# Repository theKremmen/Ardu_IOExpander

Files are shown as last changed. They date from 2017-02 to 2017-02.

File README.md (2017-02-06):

Ardu_IOExpander README.
# A Really Poor Man's Programmable Logic Controller
The library plc.h/plc.cpp together with the associated IOExpander board implement a small open source/hw logic simulator. It is free for any use but comes with no warranties of any kind.
The functionality is open ended such that it is easy to implement additional logic blocks or port the whole gizmo to a more powerful platform (Arduino Due, ST Nucleo, maybe?).

## Configuring the PLC

Configure the PLC by editing the settings in "plcconfig.h" as follows:

**TIMERTICK:** ( default `#define TIMERTICK 1000 `).

The resolution of the timers in components that time something.
The interval is given in microseconds, thus smaller is quicker.
The default value 1000 is one tick every millisecond.
All components share the same tick so select a value that is small enough but no smaller. Too small interval will overload the processor

**SPICLOCK:** ( default `#define SPICLOCK 1000000` )

The clock rate of the SPI serial clock that transfers input and output bits. Default is 1000000 i.e. 1 MHz. There should be no need to adjust this but you may if there is a need.

**BITSPACE:** ( default `#define BITSPACE 32` )

Memory space allocated for bit variables of the "ladder" logic One bit of memory is allocated for each bit variable. You can have bit variables numbered from 0 to (8 * BITSPACE)-1 E.G. if BITSPACE = 32, then your bit index goes from 0 to 255.

NOTE!: The software assigns the physical input signals to bits 0...15 and bits 16...31 to the physical OUTPUTS. The rest are freely available for programming.
You may use OUTPUTS as inputs to logic elements, but you may **NOT** use INPUTS ( bits 0 ... 15) as outputs. (You can, but it won't work).

    #if BITSPACE <= 32
    typedef uint8_t logicBit;	// type for bit variable references
    #else
    typedef uint16_t logicBit;
    #endif
    
Also note that if you specify a bitspace > 32 bytes in size, the size of the bit reference changes fron uint8_t to uint16_t. This has not been tested so surprises are possible.

**INTSPACE:** ( default `#define INTSPACE 16` )

Memory space allocated for numeric variables related to timing, counting etc.

One uint16_t is allocated for each numeric. Be sure to check the number of variables a logic component reserves. As a rule, the bit operations do not reserve any numeric variables, neither do static timers or counters (where the timing or count is constant).

Variable timers and counters need 1 or more. A multiplexer uses 3 or 5

    typedef uint8_t numeric;	// type for numeric variable references

**MAXTIMERS:** ( default `#define MAXTIMERS 8` )

The maximum number of timers reserved for the program
Make sure this number is equal or larger than the actual number of timers used by all timing components together.
As a general rule, any delay or pulse will use 1 timer.

**MAXCOMPONENTS:** (default `#define MAXCOMPONENTS 64` )

The maximum number of components allowed in the program. 
The list of components you create is maintained in a fixed size pointer array to avoid dynamic allocation and to minimize the list iteration runtime.

Make sure this number is larger or equal to the actual number of all ladder components in your application (anything you create using 'new').

**INVERT_INPUTS:** ( default `#define INVERT_INPUTS` )

Optionally you can invert the sense of all inputs by defining this (the default is `#define`d )
All input '1's will turn to '0's and vice versa.

The IOExpander physical inputs are active low with internal pullup. Unconnected, the input will be pulled to +5V, i.e. '1' or 'high' and the LED will be dark. That is what the program sees if there is nothing connected to the input. The input LED illuminates when the input signal wire is grounded. This causes the program to read a '0' from the input. It works but reversing the input in the program makes it easier for the programmer. Also, the logic modules are clocked on signal rising edges.

So, when the inputs are inverted, grounding an input pin will cause the program to see a logic '1' in the corresponding input signal.

## Arduino

You need to install an ***original Arduino Micro*** or an ***exact clone***. Only those will have the SPI signals in the module pins. This feature is not configurable, so take care. There are lots of various "Arduino Micro Pro" modules and similar with different pinout in eBay and elsewhere - **those will not work!** Specifically, you cannot use an Arduino Nano as it does not have the necessary SPI signals in the pinout.

Install the Arduino so that the USB connector faces the board edge. You can solder the Arduino directly on the board or use a set of female headers if you wish to remove the module at some time. Programming can be done with everything in place, though.

## Power and signal wiring

1. Connect the supply ( +12VDC ) to the 2 position connector block in the lower middle of the board (when oriented so that the Ardu USB connector is facing up). Positive wire is the left one, ground the right. The supply is protected against reversed polarity.

2. Connect the sensors to the 3 pin headers on the left. The pins are marked on the silkscreen thus: [+ s -] where +: +5V supply to an active sensor; s: input signal ( 0...+5V ) to the PLC; -: ground. The input signal activated upon grounding the signal pin. Connecting the signal pin to +5V does nothing, but take care not to short the +5V and ground pins!

3. Connect the outputs to the right hand side 2 pin connectors. If the polarity matters, the positive pin is on the right when looking towards the board from outside. Take care not to short the positive pins to ground as there is no overcurrent protection on the expander board! (one hopes there is a current limit in the +12V supply you use).

## Bonus I/O

Most of the regular Arduino Micro digital and analog I/O signals have been brought out next to the Ardu module into normal through hole pads.

Digital signals D4 ... D10 can be found on the right side in a .1" pin header with a ground pin topmost. Use as you please with an extra header or solder the wires directly on board.

Similarly, analog signals A0 ... A5 can be found on the left side in a 3 pin header each. Pin 1 (rightmost, square pad) of each header is +5V for a pot or sensor or whatever, and the leftmost pin (3) is ground. The analog input is from pin 2 and there is a small RC lowpass connected to each input. Again, to avoid magic smoke do not short the +5V pins.

Be aware that the Arduino analog signals are pretty noisy and the base electronics don't really address that issue. So you need to take that into account when designing a PLC app that uses the analog values for something.

A solder pad to the left of the analog inputs, marked as 'Vref', is connected (surprise) to the analog reference pin of the MCU. Use as you wish or leave open. Also, close by is a pad marked 'D201' that connects to I/O pin D13 and the LED on board the Arduino. Now you can easily replicate the LED! Finally, on the other side of the Ardu there is a pad 'SS' that connects to USART_RXLED/SS. If you find a use for that, go right ahead.
 
Additinally, the board includes placeholders for I2C connectors and and SPI expansion to enable connecting units in series. These have not been tested but there should be no reason why they wouldn't work. If you need them, presumably you know what to do. Look to the right side of the Ardu module and you will find 2 solder bridges marked 'I2C TERM'. Shorting those will activate the 4.7k pull-up termination for the I2C bus.

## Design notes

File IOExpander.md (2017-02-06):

# Tosi Köyhän Miehen logiikkasimu Arduinolle

plc.h/plc.cpp yhdessä IOExpander-laajennuspiirilevyn kanssa toteuttaa pienen avoimen logiikkasimulaattorin.
Määriteltyjä toimintoja on mahdollista muokata tarpeen mukaan sekä toteuttaa kokonaan uusia toimintoja.
Seuraavassa lyhyt läpikäynti ohjelman ominaisuuksista ja toiminnasta.

## PLC:n konfigurointi

Konfigurointi tehdään asettamalla tiedoston "plcconfig.h" sisältämät #define -määritykset haluttuihin arvoin.
Niiden merkitys on seuraava:

TIMERTICK: ( oletusarvo #define TIMERTICK 1000 )
Logiikkaohjelman käyttämien ajastimien ja pulssigeneraattoreiden aikaresoluutio millisekunteina.
Ohjelma ei mitenkään testaa annetun arvon järkevyyttä, joten kannattaa varoa laittamasta liian pientä arvoa.
Totuus selviää kyllä kokeilemalla.

SPICLOCK: ( oletusarvo #define SPICLOCK 1000000 )
Tuloja ja lähtöjä ohjaavien siirtorekisterien kellotaajuus. Oletusarvo on 1MHz eikä tätä ole normaalisti tarvetta muuttaa.

BITSPACE: ( oletusarvo #define BITSPACE 32 )
Logiikan bittimuuttujille varattu muistitila. Jokainen muuttuja vie yhden bitin verran tilaa muistissa (mikä yllätys).
Ohjelma pystyy siis käsittelemään bittejä 8 * BITSPACE määrän, eli oletusarvoisesti 256 bittiä (signaalia).
Huomaa, että fyysiset tulosignaalit luetaan bittimuuttujiin 0...15 ja fyysiset lähtösignaalit kirjoitetaan bittimuuttujista 16...31.
Huomaa myös, että mikäli BITSPACE > 32, kaikki ohjelman signaaliviittaukset muuttuvat 8-bittisistä referensseistä 16-bittisiksi eikä tätä ole kunnolla testattu:
    
    #if BITSPACE <= 32
    typedef uint8_t logicBit;	// type for bit variable references
    #else
    typedef uint16_t logicBit;
    #endif
    
INTSPACE: ( oletusarvo #define INTSPACE 16 )
Logiikan numeerisille muuttujille varattu tila. Kaikki numeeriset muuttujat ovat etumerkittömiä 16-bittisiä kokonaislukuja ( uint16_t ). Muuttujatilaa kannattaa varata riittävästi, mutta ei liioitellusti koska RAM-muisti on kortilla pikku Arduinossa. Kunkin logiikkamodulin tarvitsema tilavaraus on mainittu sen esittelyssä.

MAXTIMERS: ( oletusarvo #define MAXTIMERS 8 )
Tilavaraus logiikan ajastimille. Varaus tehdään samalla periaatteella kuin yllä.

MAXCOMPONENTS: ( oletusarvo #define MAXCOMPONENTS 64 )
Tilavaraus komponenttilistalle. Määrittelemässäsi logiikkaohjelmassa voi olla enintään näin monta yksittäistä modulia. Älä ylitä tätä lukemaa!
Kaikki Arduinon setup():issa luodut logiikkalohkot lisätään yksinkertaiseen jonolistaan, josta ne suoritetaan peräjälkeen jokaisella loop():in kierroksella. Toteutus on tehty näin yksinkertaisuuden ja suoritustehokkuuden takia. Joudut kuitenkin olemaan lievästi huolellinen, eli laskemaan, että määrittelemäsi lohkot mahtuvat listalle. Jokainen lohko siis vaatii yhden listaelementin. 

INVERT_INPUTS: ( oletusarvo #define INVERT_INPUTS )
Mikäli määritys INVERT_INPUTS on tehty, jokainen tulosignaali käännetään ympäri, eli looginen '1' muuttuu '0':ksi ja päinvastoin.
HUOMAA, että IOExpanderin tulosignaali on aktiivinen alaspäin, eli ledi valaisee kun tulosignaalin tila on '0'.
Kun signaali on '1' tai kytkemätön, ledi ei pala. Ohjelmaan välittyy kuitenkin kyseinen tila, eli kytkemätön tulo luetaan '1'-tilaiseksi. Useimmiten tämä ei ole toivottua, vaan signaali halutaan tulkita niin, että se on '1' kun ledi valaisee. Siispä invertoidaan tulot jolloin ajatus toteutuu. Jos invertointia EI haluta käyttää, riittää että tämä #define kommentoidaan pois: //#define INVERT_INPUTS

## Arduino

PLC haluaa expanderikortille Arduino Micron. Ole tarkkana minkä kapineen kortille länttäät, koska kaikki eBay-tavara yms ei ole originaalispeksin mukaista. Käytetyn Ardun pinnijaon pitää olla 1:1 originaali Arduino Micron kanssa - esim. Arduino Nano EI KÄY. Micro on valittu koska vain siitä saa välttämättömän SPI-väylän suoraan ulos pinneistä. Ardu asennetaan siten, että sen USB-liitin tulee kohti piirilevyn ulkoreunaa. Moduli nvoi juottaa suoraan kiinni tai mikäli haluaa varmistella, niin voi käyttää myös korokeheadereita jolloin Ardun saa vielä irtikin.
Arduinon voi ohjelmoida etuykäteen, tai se onnistuu myös piiri kiinnitettynä jolloin sitä varten irroitettavuutta ei tarvita. 

## Sähköiset kytkennät

1. Syöttöjännite ( n. 12V) kytketään kortin "alareunassa" keskellä olevaan pieneen riviliittimeen. Positiivinen johto vasemmalle, maa oikealle. Liitäntä on suojattu väärää napaisuutta vastaan.
2. Anturit kytketään vasemman reunan 3-pinnisiin pistoliittimiin. Liittimet on merkitty silkkipainoon [+ s -] ja samassa järjestyksessä signaalit ovat: +: +5V syöttö anturille; s: tulosignaali (+5V <-> 0V); -: 0V syöttö anturille. Tulosignaali aktivoituu kun s-pinni maadoitetaan - pinniin. s-pinnin kytkeminen + pinniin ei tee mitään, mutta VARO oikosulkemasta + ja - pinnejä keskenään.
3. Lähdöt kytketään oikean reunan 2-pinnisiin liittimiin. Oletus on, että kuorma on solenoideja tms joiden napaisuudella ei ole väliä, mutta jos on, niin lähdön +-napa on piirilevyn ulkoreunasta sisäänpäin katsoen oikeanpuoleinen pinni. Vasen menee kytkinfetille ja siitä maahan. VARO siis oikosulkemasta oikeanpuoleisia pinnejä maahan koska niissä on koko ajan jännite ja laitteessa ei ole ylivirtasuojausta (toivottavasti käyttämässäsi virtalähteessä on).

## Lisäkytkennät

Ardu Micron normaalit digitaaliset ja analogiset I/O-piirit on tuotu expanderille Ardumodulin viereen juotosreikiin.
Digitaalisignaalit D4 ... D10 on tuotu suoraan 0,1" reikäriviin jonka viimeinen reikä (D10 puoleinen pää) on maajännite. Tähän voi kolvata johtimia suoraan tai laittaa headerin protojohtoja varten.
Vastaavasti analogisignaalit A0 ... A5 on tuotu Ardun vasemmalle puolelle kukin 3-reikäiseen headerpaikkaan. Headerin pinni 1 (neliötäppä, oikeanpuoleinen) on +5V syöttö esim potikalle, pinni 3 (vasen) on maa.  Analogisignaali luetaan keskipinnistä 2 ja siihen on kytketty pieni RC-suoto nappaamaan pahimmat jännitepiikit pois. HUOMAA kuitenkin, että analogisignaalit kohisevat aina eikä logiikkaohjelman analogitulolohkossa ole varsinaista suodatusta koska se on raskasta puuhaa prosessorille. Älä siis kuvittele, että signaalit olisivat ideaalisen rauhallisia, vaikka olisit kytkenyt pelkän potikan tuloon.
Juotostäppä Aref edellisten vasemmalla puolella on kytketty (yllätys) prosessorin analogireferenssiin. Sitä voi käyttää datalehden mukaisesti mikäli taretta ilmenee.
Edellisen vieressä on toinenkin tuotostäppä, merkattu D201. Se on kytketty Arduinon digitaalilähtöön D13, joka puolestaan on kytketty Ardumodulin lediin.
Piirilevyn laidasta Ardun toisella puolella löytyy vielä täppä "SS" joka on kytketty signaaliin RX_LED/SS.

Edellisten lisäksi expanderilta löytyy liitinpaikat I2C-väylälle ja SPI-väylän laajennukselle, tarkoituksena mahdollistaa useampien expanderien kytkeminen ryhmään. Näitä ei ole testattu mitenkään, joskaan ei ole mitään erityistä syytä miksi eivät toimisi. Joka niitä tarvitsee osaa varmaan käyttää niitä ilman erityisempää ohjeistusta tässä. Ardun oikealta puolelta löytyy 2 kpl juotos-oikosulkutäppiä jotka merkattu "I2C TERM.". Juottamalla nämä umpeen saadaan voimaan I2C-väylän 4,7kohm ylösvetoterminointi.

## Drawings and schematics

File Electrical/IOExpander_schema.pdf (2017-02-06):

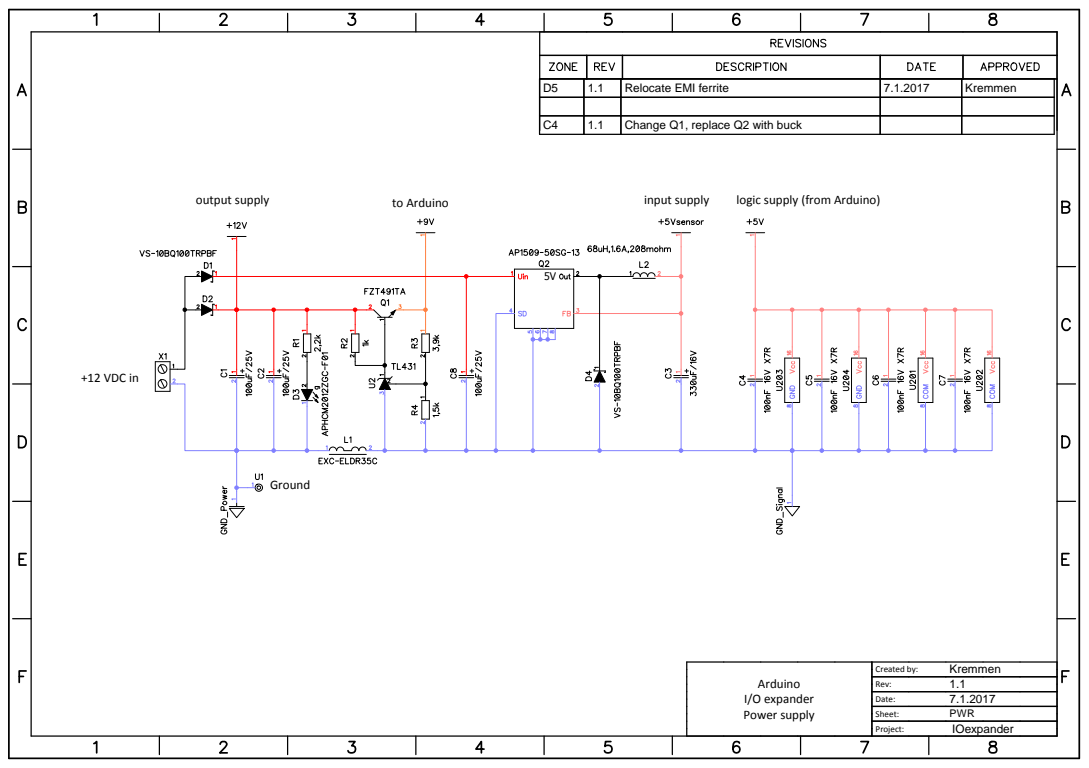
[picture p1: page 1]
+12 VDC in; to Arduino output supply; input supply; logic supply (from Arduino); Ground; Kremmen; PWR; Created by:; Rev:; Date:; Sheet:; Kremmen 1.1 7.1.2017; Project:; IOexpander; Arduino I/O expander Power supply

Relocate EMI ferrite

Change Q1, replace Q2 with buck

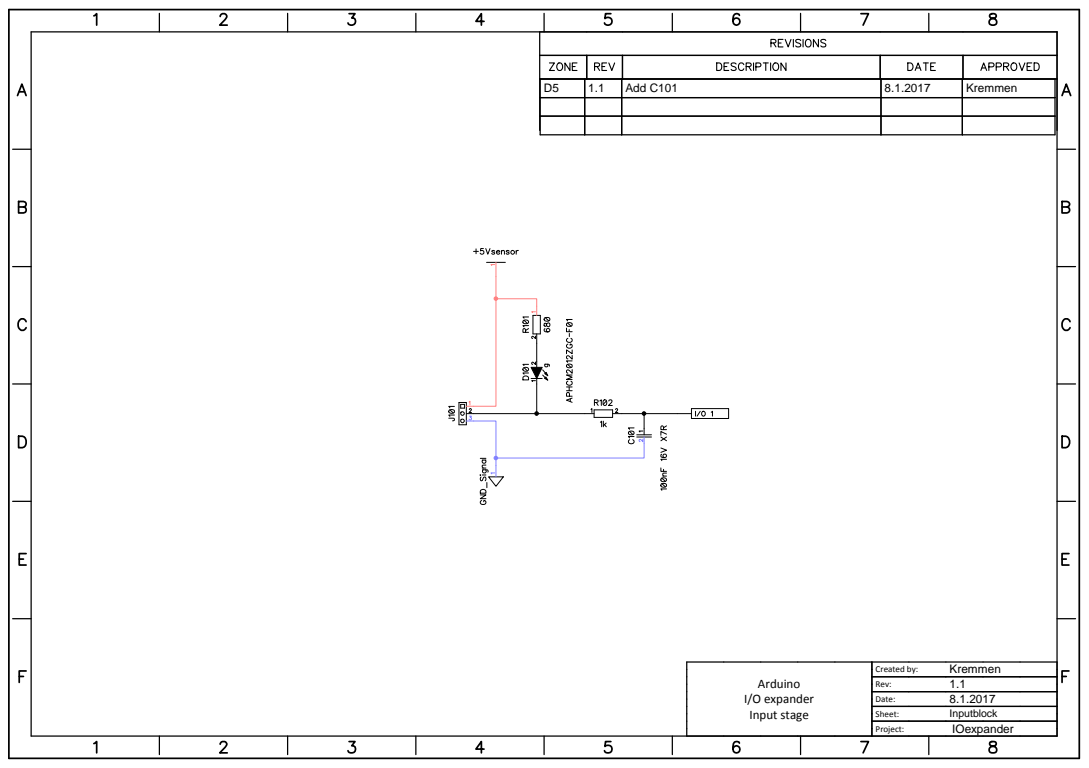
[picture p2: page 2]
Add C101; Kremmen; Inputblock; Created by:; Rev:; Date:; Kremmen 1.1 8.1.2017; Arduino I/O expander Input stage

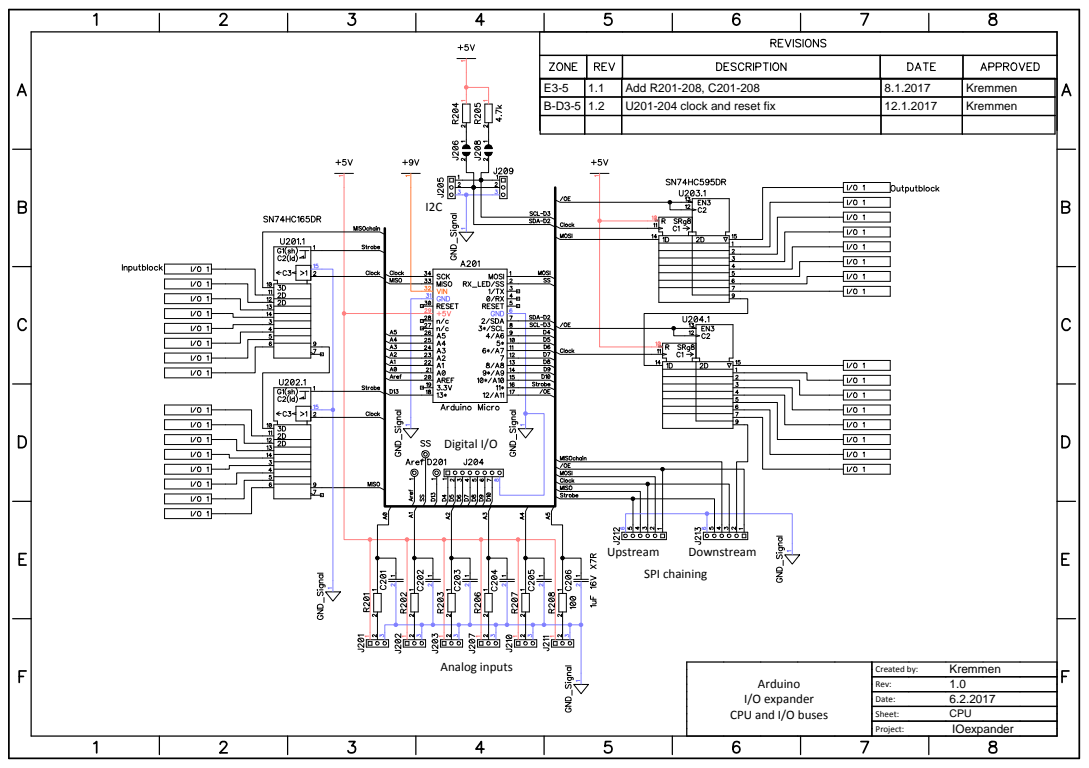
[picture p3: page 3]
Upstream; Downstream; SPI chaining; Analog inputs; Digital I/O; CPU; Created by:; Rev:; Date:; Kremmen 1.0 6.2.2017

E3-5 | 1.1 | Add R201-208, C201-208 | 8.1.2017 | Kremmen
B-D3-5 | 1.2 | U201-204 clock and reset fix | 12.1.2017 | Kremmen

Arduino
I/O expander
CPU and I/O buses

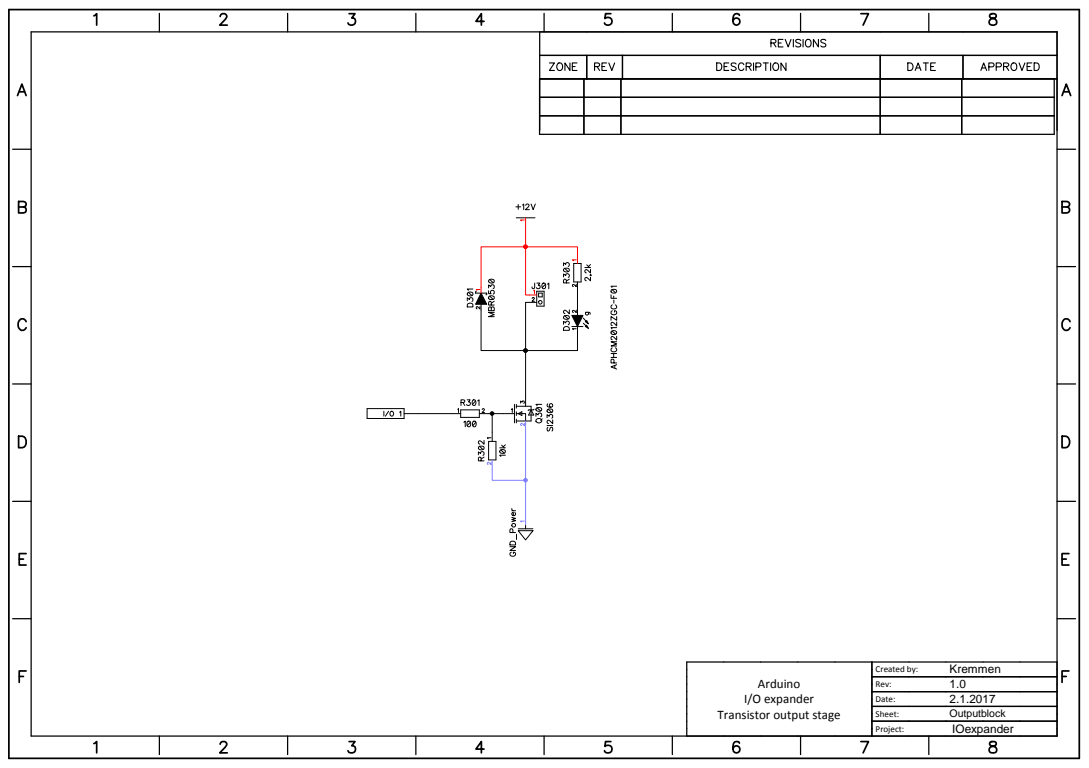
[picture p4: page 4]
Outputblock; Created by:; Rev:; Date:; Kremmen 1.0 2.1.2017

Arduino
I/O expander
Transistor output stage

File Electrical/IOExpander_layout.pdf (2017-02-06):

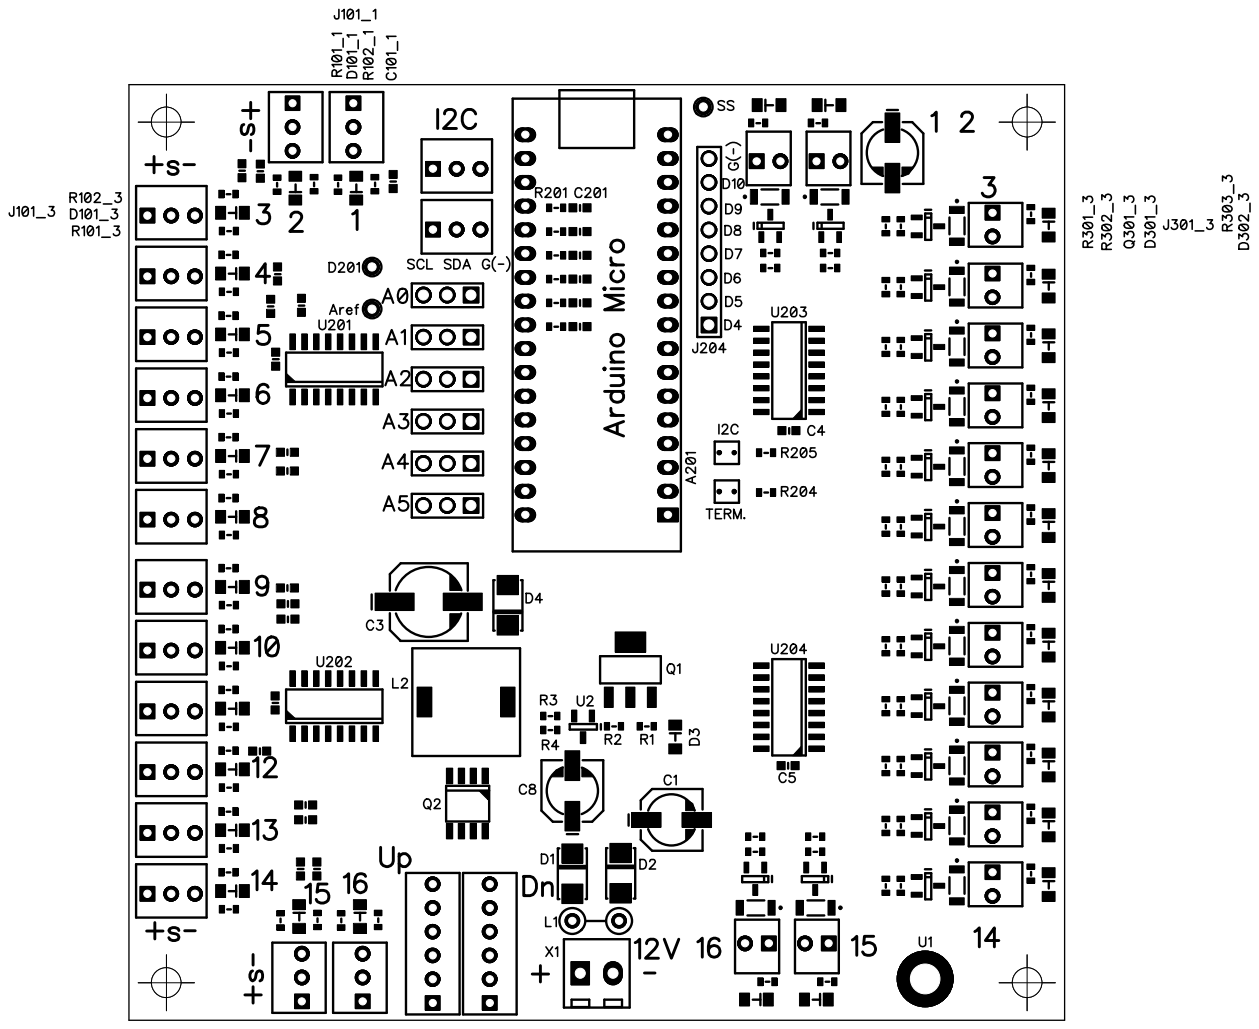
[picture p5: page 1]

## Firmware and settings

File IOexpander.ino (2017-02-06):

// Arduino IO expander using Arduino Micro
// Author: Kremmen 12.1.2017
// Tämä on pieni esimerkkisovellus jossa on käytetty useimpia, mutta ei välttämättä kaikkia
// plc-simulaattorin toiminnallisia lohkoja.
// Lopullinen totuus selviää tiedostoja plc.h ja plc.cpp lukemalla, siellä on kommentoitu tarkemmin kunkin
// toiminnon olemusta.

// Arduinon käännösympäristö vaatii nämä esittelyt vaikkei niitä käytetä tässä
#include <TimerOne.h>
#include <SPI.h>

// Varsinainen logiikkasimu on täällä
#include "plc.h"


// Arduinon normaali setup: Koko logiikkaohjelma määritellään setupissa luomalla tarvittavat logiikkalohkot
// Luonti tapahtuu C++ -kielen muistioperaattorilla 'new'. Älä määrittele lohkoja muilla tavoilla koska
// vain tämä tapa on testattu toimivaksi
// Kunkin lohkon parametrit viittaavat bittisignaaleihin ja/tai numeerisiin muuttujiin. Viittaus on kunkin
// järjestysnumero k.o. muuttuja-avaruudessa. Kts tarkemmin "plcconfig.h".
// Tämä esimerkki ei tee mitään järkevää, sen tarkoitus on vain demota kuinka ohjelma rakenetaan lohkoista.

void setup()
{
	CList.begin();		// aloita aina tällä lauseella! Se mm. alustaa kaikki lähdöt passivitilaan mahdollisimman nopeasti

	Serial.begin(115200);
	Serial.println("ArduPLC v 1.0");


	setBit(255, true);
	setBit(254, false);
	setInt(15, 511);
	setInt(14, 100);

// Ensimmäinen monostabiili; tulosignaalia (bitti 0) ei ole lukittu 
	new Astable( 255, 16, 75, 425 );	// Astabiili (värähtelijä): enable bitistä 255, lähtö bittiin 16; päällä 75ms, pois 425 ms (jaksonaika = 75 + 425 = 500ms)
	new Logic2( 16, 0, 31, AND );		// bit 31 = bit 16 AND bit 0
	new Monostable( 31, 18, 500 );		// Monostabiili: liipaisu bitti 31, lähtö bittiin 18, pulssin kesto 500 ms

// Toinen monostabiili, tulosignaali (bitti 0) on lukittu bistabiililla
	new Bistable( 0, 30, 32 );			// Bistabiili: lyhytkin pulssi asetusbitissä (bitti 0) asettaa ja pitää lähdön. Bitti 30 nollaa lähdön
	new Logic2( 16, 32, 30, AND );		// bit 30 = bit 16 AND bit 32
	new Monostable( 30, 19, 500 );		// Monostabiili: liipaisu bitti 30, lähtö bittiin 19, pulssin kesto 500 ms

// Analogisen kanavan sisäänluku ja skaalaus. Viivepulssi analogilukeman perusteella
	new AnalogIn( 0, 1, 100.0, 2.0 );	// AnalogIn: luetaan A-kanava 0, tulos numeeriseen muuttujaan 1, analogisignaalin offset 100.0, kerroin 2.0
	new VDelay(30, 254, 29, 1, 1 );		// Variable Delay: määräpituinen, määräviivästetty pulssi. liipaisu bitistä 30, reset bitti 254, lähtö bittiin 29.
										// Viive luetaan numeerisesta muuttujasta 1, pulssin pituus numeerisesta muuttujasta 1 (sama)

// Lukuarvojen vertailu
	new CompareNumeric(1, 15, 28, GT);	// Numeeristen arvojen vertailu: Verrataan muuttujia nro 1 ja 15. Tulos bittiin 28.
										// Vertailuoperaatio on "GT" eli "Greater Than".

// Bitin valinta kahdesta
	new BitMux2_1(16, 18, 28, 20);		// Valinta kahdesta: bitti 28 valitsee joko bitin 16 tai bitin 18 lähtöbittiin 20
	
// pulssien laskenta ja indikaatio
	new UpCounter(16, 1, 2);			// lasketaan bitin 16 (astabiilin lähtö) nousevia reunoja numeeriseen muuttujaan 2
	new Calc2(1,14,3,MINUS);			// Vähennetään analogilukemasta 100 (muuttuja 14) ja talletetaan muuttujaan 3
	new CompareNumeric(2, 3, 21, GE);	// Verrataan laskurin lähtöä ja analogikanavan vähennettyä lukemaa. Tulos bittiin 21
	new Monostable(21,22,1000);			// Kun laskuri muuttuu isommaksi, annetaan pulssi bittiin 22

}

void loop() {
	CList.execute();
}

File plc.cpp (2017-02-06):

/*
 * plc.cpp
 *
 * Created: 11.1.2017 9:34:45
 * Author: Kremmen
 * Implementation of the Various "relays" - pulse, delay, set/reset etc declared in plc.h

 * This library simulates the elements of a PLC ladder diagram
 * There is no user interface, the user must specify the "ladder" in the main program
 * by creating all the components and then connecting them together
 * using bit and variable numbers (indexes) in the component call arguments.
*/

#include "plc.h"
#include <SPI.h>
#include <TimerOne.h>

#define UINT16_MAX 65535

// Arduino outputs for the shift register strobe latches
#define OE 12		// 595 output strobe/enable
#define STROBE 11	// 165 load/shift strobe

uint8_t bits[BITSPACE];		// allocation for the bit variables
uint16_t ints[INTSPACE];	// allocation for the integer variables

SPISettings spiSettings( SPICLOCK, MSBFIRST, SPI_MODE0 );

uint8_t timerCount = 0;
volatile uint32_t timers[MAXTIMERS];

// Interrupt handler for the PLC timers
void tISR() {
uint8_t cnt;
	for ( cnt = 0; cnt < timerCount; cnt++ ) {
		if ( timers[cnt] > 0 ) timers[cnt]--;
	}
}

// Debug help to list the bit variables (and timers). Not used during normal operation
void listBits() {
uint8_t cnt;
	for ( cnt = 0; cnt < BITSPACE; cnt++ ) {
		if ( cnt % 8  == 0) Serial.println();
		Serial.print(bits[cnt]);
		Serial.print(" ");
	}
	Serial.println();
}
void listTimers() {
	uint8_t cnt;
	Serial.println(timerCount);
	for ( cnt = 0; cnt < MAXTIMERS; cnt++ ) {
		if ( cnt % 8  == 0) Serial.println();
		Serial.print(timers[cnt]);
		Serial.print(" ");
	}
	Serial.println();
}

// Helper function to extract a bit from the bitspace
bool Bit(logicBit bit) {									// Bit interrogation routine
	return bits[ bit / 8 ]	 & (1 << (bit % 8));
};

// Helper function to set/reset a bit in the bitspace
void setBit( logicBit bit, bool state ) {
	state ? bits[bit/8] |= (1<<(bit%8)) : bits[bit/8] &= ~(1<<(bit%8));
}

int16_t Int(uint8_t intIndex) { return ints[intIndex]; }

void setInt( uint8_t intIndex, int16_t Value ) {
	ints[intIndex] = Value;
}

// PLC Component classes:
//-------------------------
// (for comments, see header "plc.h"

ComponentList CList;


Component::Component(logicBit inPut, logicBit outPut) {
	inBit = inPut;
	outBit = outPut;
	state = state_OFF;
	CList.add(this);
}

void Component::execute() {

}



Logic2::Logic2(logicBit inPut, logicBit inPut2, logicBit outPut, logicFunction func):Component(inPut, outPut) {
	inBit2 = inPut2;
	lFun = func;
}

void Logic2::execute() {
	switch ( lFun ) {
		case AND: setBit(outBit, Bit(inBit) && Bit(inBit2)); break;
		case NAND: setBit(outBit, !(Bit(inBit) && Bit(inBit2))); break;
		case OR: setBit(outBit, Bit(inBit) || Bit(inBit2)); break;
		case NOR: setBit(outBit, !(Bit(inBit) || Bit(inBit2))); break;
		case XOR: setBit(outBit, Bit(inBit) ^ Bit(inBit2)); break;
	}
}

Calc2::Calc2(numeric inPut, numeric inPut2, numeric outPut, numericFunction func):Component(inPut, outPut) {
	inBit2 = inPut2;
	nFun = func;
}

void Calc2::execute() {
int32_t tmpint;
	switch ( nFun ) {
		case PLUS: {
			tmpint = ints[inBit] + ints[inBit2];
			if ( tmpint > UINT16_MAX ) ints[outBit] = UINT16_MAX;
			else ints[outBit] = tmpint;
			break;
		}
		case MINUS: {
			tmpint = ints[inBit] - ints[inBit2];
			if ( tmpint < 0 ) ints[outBit] = 0;
			else ints[outBit] = tmpint;
			break;
		}
		case MUL: {
			tmpint = ints[inBit] * ints[inBit2];
			if ( tmpint > UINT16_MAX ) ints[outBit] = UINT16_MAX;
			else ints[outBit] = tmpint;
			break;
		}
		case DIV: {
			ints[outBit] = ints[inBit] / ints[inBit2];
			break;
		}
		case MOD: {
			ints[outBit] = ints[inBit] % ints[inBit2];
		}
	}
}

Bistable::Bistable(logicBit inPut, logicBit inPut2, logicBit outPut):Component(inPut, outPut) {
	inBit2 = inPut2;
}

void Bistable::execute() {
	if ( Bit(inBit) ) setBit( outBit, true );
	else if ( Bit(inBit2) ) setBit( outBit, false );
}

Astable::Astable(logicBit inPut, logicBit outPut, uint32_t Time1, uint32_t Time2):Component(inPut, outPut) {
	onTime = Time1;
	offTime = Time2;
	timerIndex = timerCount++;
}

void Astable::execute() {
bool inp;
uint32_t tmpTimer;
	inp = Bit(inBit);
	if ( inp) {	// enabled, component is active
		if ( !prevInput ) {	// enable turned on just now; initialize cycle
			state = state_ON;
			setBit(outBit, true);
			cli();
			timers[timerIndex] = onTime;
			sei();
		}

		cli();	// get a copy of the timer
		tmpTimer = timers[timerIndex];
		sei();

		if ( tmpTimer == 0 ) {	// if timer expired, flip the cycle on-off-on...
			if ( state == state_ON ) {
				state = state_OFF;
				setBit( outBit, false);
				cli();
				timers[timerIndex] = offTime;
				sei();
			}
			else {
				state = state_ON;
				setBit( outBit, true);
				cli();
				timers[timerIndex] = onTime;
				sei();
			}
		}
	}
	else {	// not enabled, turn off if active
		if ( state == state_ON ) {
			setBit( outBit, false );
			state = state_OFF;
		}
	}
	prevInput = inp;
}

Monostable::Monostable(logicBit inPut, logicBit outPut, uint32_t pulseTime):Component(inPut, outPut) {
	setTime = pulseTime;
	prevInput = false;
	timerIndex = timerCount++;
}

void Monostable::execute() {
uint32_t tmpTimer;
bool inp;
	inp = Bit(inBit);
	if ( inp ) {
		if ( !prevInput ) {	// rising edge
			setBit(outBit, true);
			state = state_ON;
			cli();
			timers[timerIndex] = setTime;
			sei();
		}
	}
	if ( state == state_ON ) {
		cli();
		tmpTimer = timers[timerIndex];
		sei();
		if ( tmpTimer == 0 ) {
			setBit(outBit, false);
			state = state_OFF;
		}
	}
	prevInput = inp;
}

VMonostable::VMonostable(logicBit inPut, logicBit outPut, uint8_t pulseTimeIndex):Component(inPut, outPut) {
	setTimeIndex = pulseTimeIndex;
	prevInput = false;
	timerIndex = timerCount++;
}

void VMonostable::execute() {
	uint32_t tmpTimer;
	bool inp;
	inp = Bit(inBit);
	if ( inp ) {
		if ( !prevInput ) {	// rising edge
			setBit(outBit, true);
			state = state_ON;
			cli();
			timers[timerIndex] = bits[setTimeIndex];
			sei();
		}
	}
	if ( state == state_ON ) {
		cli();
		tmpTimer = timers[timerIndex];
		sei();
		if ( tmpTimer == 0 ) {
			setBit(outBit, false);
			state = state_OFF;
		}
	}
	prevInput = inp;
}

DnCounter::DnCounter(logicBit clock, logicBit reset, logicBit outPut, uint16_t initCount):Component(clock, outPut) {

	inBit2 = reset;
	initialCount = initCount;
	count = initialCount;
	prevInput = false;
}

void DnCounter::execute() {
bool tmpBit;
	tmpBit = Bit(inBit);
	if ( Bit( inBit2 ) ) {
		setBit(outBit, false);
		count = initialCount;
	}
	else {
		if ( tmpBit && !prevInput ) {
			if ( count > 0 ) count--;
			if (count == 0) {
				setBit( outBit, true );
			}
		}
	}
	prevInput = tmpBit;
}

UpCounter::UpCounter(logicBit clock, logicBit reset, numeric outPut):Component(clock, outPut) {
	inBit2 = reset;
	ints[outBit] = 0;
	prevInput = false;
}
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

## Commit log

2017-02-06 Electical schematic
2017-02-06 Circuit schematic
2017-02-06 Electrical Schematic
2017-02-06 Gerber files for PCB fabrication
    [IOExpander.GBL, IOExpander.GBO, IOExpander.GBS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]
